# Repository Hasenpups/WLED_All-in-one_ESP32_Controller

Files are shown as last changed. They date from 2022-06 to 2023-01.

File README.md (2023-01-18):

Shield: [][cc-by-nc-sa]

This work is licensed under a
[Creative Commons Attribution-NonCommercial-ShareAlike 4.0 International License][cc-by-nc-sa].

[][cc-by-nc-sa]

[cc-by-nc-sa]: http://creativecommons.org/licenses/by-nc-sa/4.0/
[cc-by-nc-sa-image]: https://licensebuttons.net/l/by-nc-sa/4.0/88x31.png
[cc-by-nc-sa-shield]: https://img.shields.io/badge/License-CC%20BY--NC--SA%204.0-lightgrey.svg

## Donations / Spenden
If somebody wants to support me for upcoming projects :)  
- PayPal:  
- Amazon Giftcard: https://www.amazon.de/Amazon-Gutschein-per-E-Mail-Amazon/dp/B0054PDOV8 - stefan.riese@me.com

# WLED All-in-one ESP32 Controller
This board is designed to connect addressable LEDs/Neopixel strips and handle them with the WLED firmware. Other firmware can be used as well.

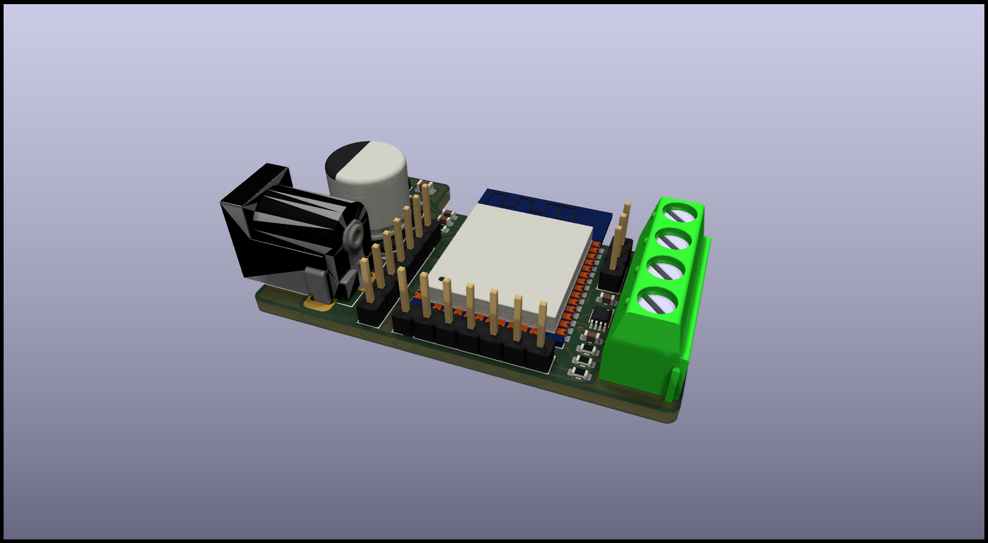
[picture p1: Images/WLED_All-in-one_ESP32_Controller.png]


## Features
- ESP32-WROOM-32E
- 5,5mm / 2,1mm barrel jack connector for input voltage
- 2 output lines for LED data and LED clock or relais
- level shifter for both outputs (3.3V -> 5V )
- resistor for data line
- support for LED strips with clock signal
- connector to flash firmware with CP2104 (3.3V, TX, RX, GND, IO0, GND)
- :heavy_exclamation_mark: Maximum 5A :heavy_exclamation_mark:
- connector for digital input (3.3V, GND, IO4) (IR remote control for example)
- connector for addon shields (GND, IO32, IO15, IO14, 3.3V, GND, SENSOR_VP)

## BOM
- 1 x WLED All-in-one ESP32 Controller presoldered from https://jlcpcb.com/

|Comment|Designator|Footprint|LCSC
|---|---|---|---
2.7K|R4|R_0603_1608Metric|C13167
100nF|C5,C6,C7|C_0603_1608Metric|C14663
47µF|C3|C_0805_2012Metric|C16780
10µF|C2,C4|C_0603_1608Metric|C19702
330|R5|R_0603_1608Metric|C23138
1000µF|C1|CP_Elec_10x10|C249474
10K|R1,R2,R3|R_0603_1608Metric|C25804
AMS1117-3.3|U1|SOT-89-3|C347256
TXS0102DCU|U3|VSSOP-8_2.3x2mm_P0.5mm|C53434
ESP32-WROOM-32|U2|ESP32-WROOM-32|C701342
LED|D1|LED_0805_2012Metric_Pad1.15x1.40mm_HandSolder|C84256
Barrel_Jack|J2|BarrelJack_Horizontal|
Screw_Terminal_01x04|J3|TerminalBlock_bornier-4_P5.08mm|
Conn_01x03_Female|J4|PinHeader_1x03_P2.54mm_Vertical|
Conn_01x07_Female|J1|PinHeader_1x07_P2.54mm_Vertical|
Conn_01x07_Female|J5|PinHeader_1x07_P2.54mm_Vertical|

- 2 x 2-pin screw terminal (https://www.amazon.de/gp/product/B08JB6SSCJ)
- 1 x Barrel Jack Adapter DS-210 (5,5mm / 2,1mm) (https://www.ebay.de/itm/182379482999)

## Wiring diagram
- https://github.com/Hasenpups/WLED_All-in-one_ESP32_Controller/blob/main/WLED_All-in-one_ESP32_Controller.pdf

## Software
- WLED: https://github.com/Aircoookie/WLED
- Sound reactive WLED: https://github.com/atuline/WLED 

## How to flash software
- Connect IO0 to GND
- Connect USB-UART bridge to 3.3V, TX, RX and GND
    - https://de.aliexpress.com/item/1005002689033373.html
    - https://www.makershop.de/module/kommunikation-module/micro-usb-uart-ttl/
- Open https://install.wled.me/
- Click "Install"
- Select COM port of USB-UART bridge
- Wait until finished

## WLED configuration
- OUT1 - IO16  
- OUT2 - IO17  
- IR receiver - IO18
- Digital microphone (SCK - IO14, WS - IO15, SD - IO32)
- Analog microphone (ADC - SENSOR_VP)
- Button input - IO26

## Addon shields
The following addon shields are available

### Microphone input
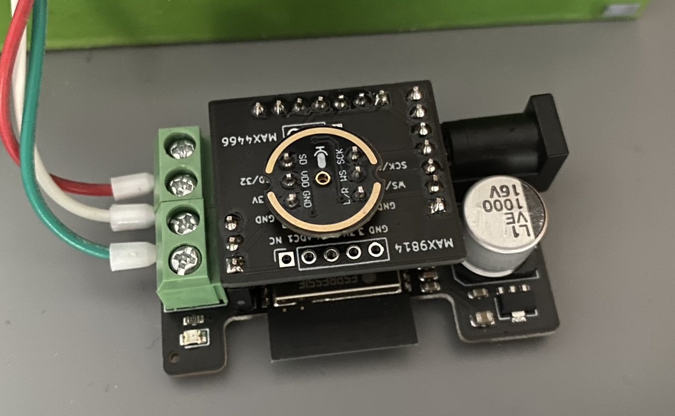
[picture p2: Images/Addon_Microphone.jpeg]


- connector for digital and analog microphones 
- INMP401 
- MAX4466 
- MAX9814 

### Prototype area
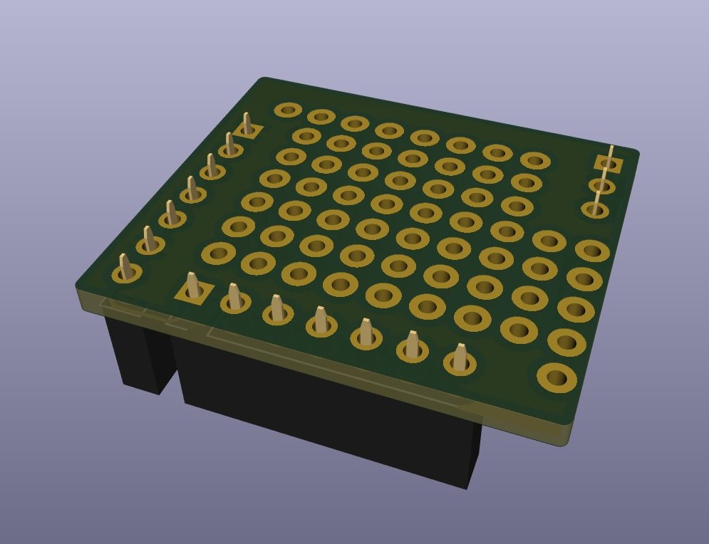
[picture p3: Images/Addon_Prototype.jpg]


### Cube builder
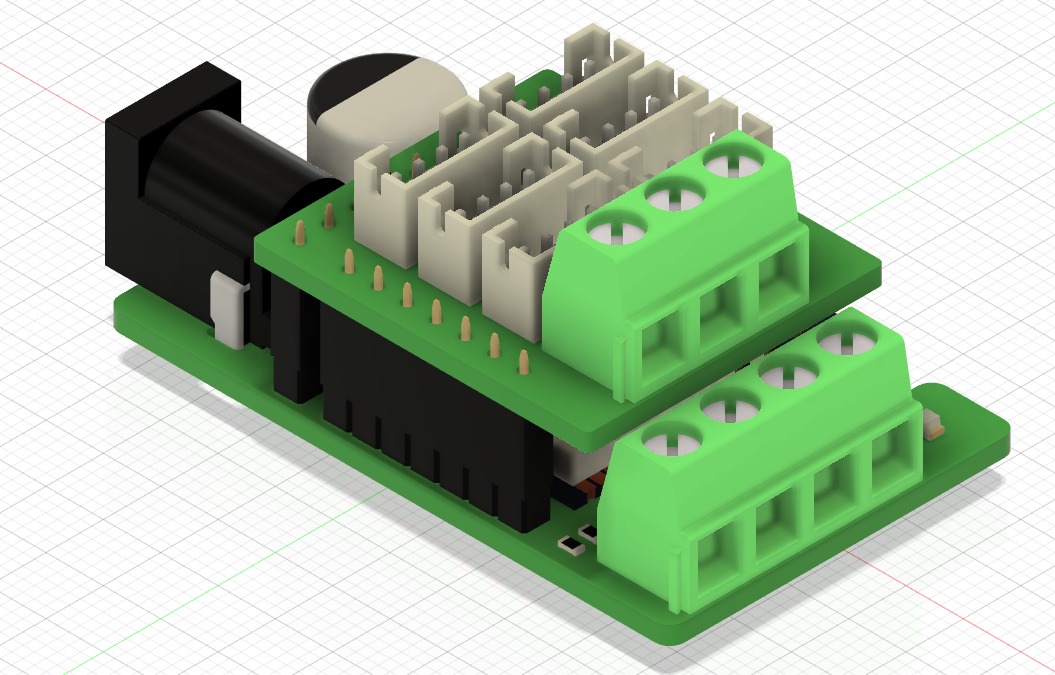
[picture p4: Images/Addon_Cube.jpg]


- 6 JST-PH connectors to add LED matrix panels to build a cube

## Case
https://www.printables.com/model/373138-wled-all-in-one-esp32-controller-housing

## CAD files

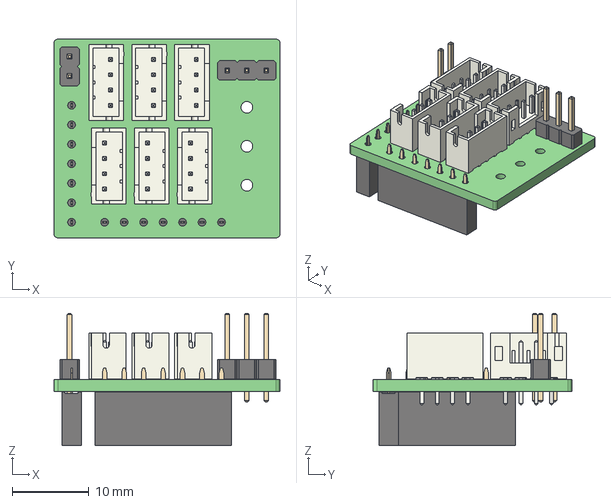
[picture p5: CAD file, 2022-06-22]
Addons/Cube/WLED_All-in-one_ESP32_Addon_Cube.step
29.5 x 25.9 x 17.2 mm
_autosave-WLED_All-in-one_ESP32_Addon_Cube PCB

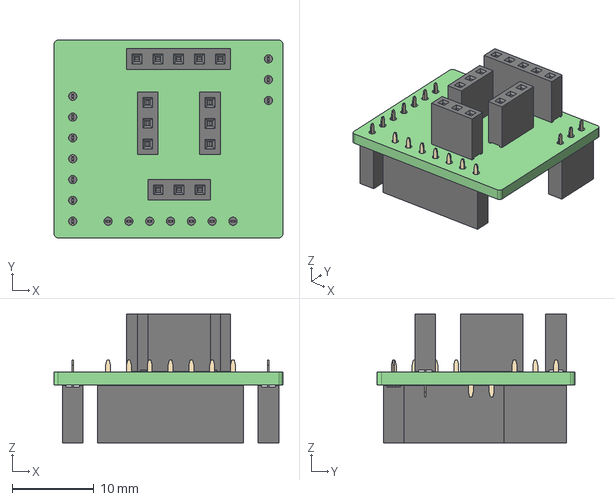
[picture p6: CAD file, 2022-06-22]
Addons/Microphone/WLED_All-in-one_ESP32_Addon_Microphone.step
27.9 x 24.1 x 15.7 mm
WLED_All-in-one_ESP32_Addon_Microphone PCB

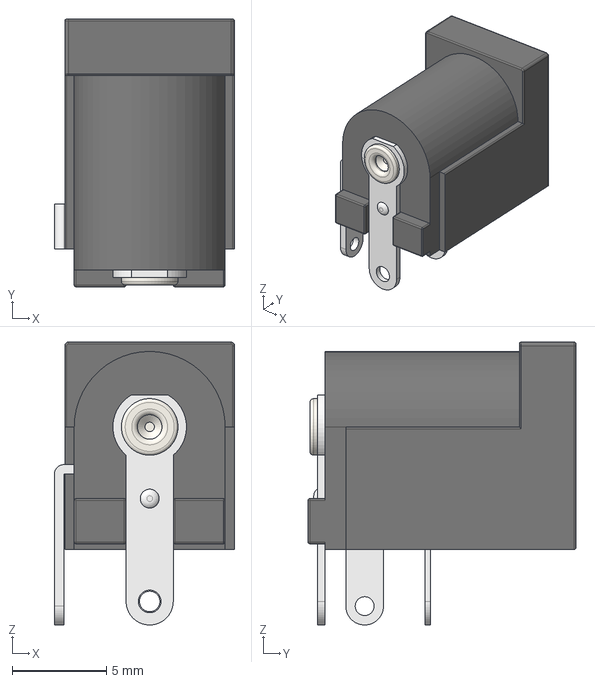
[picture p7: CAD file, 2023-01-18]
KiCad/Project_Libraries/Project_3DModels/DS-210 v1.step
9.55 x 14.2 x 15.0 mm

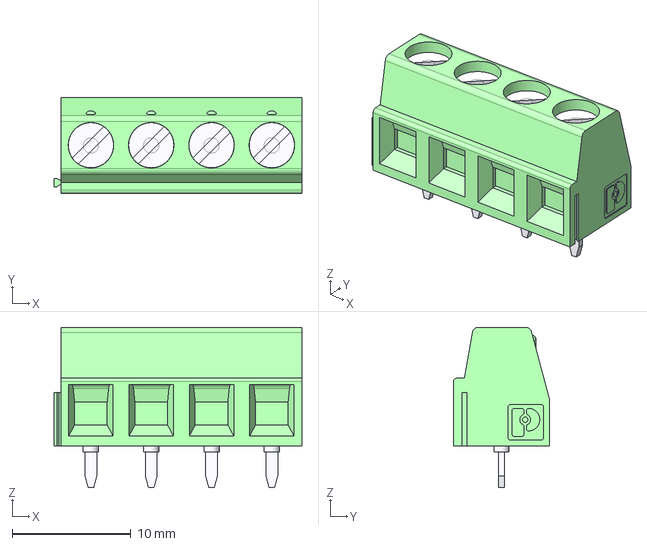
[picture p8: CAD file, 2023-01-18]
KiCad/Project_Libraries/Project_3DModels/PhoenixContact_MKDSN-1.5-4-5.08.step
20.9 x 8.10 x 13.5 mm

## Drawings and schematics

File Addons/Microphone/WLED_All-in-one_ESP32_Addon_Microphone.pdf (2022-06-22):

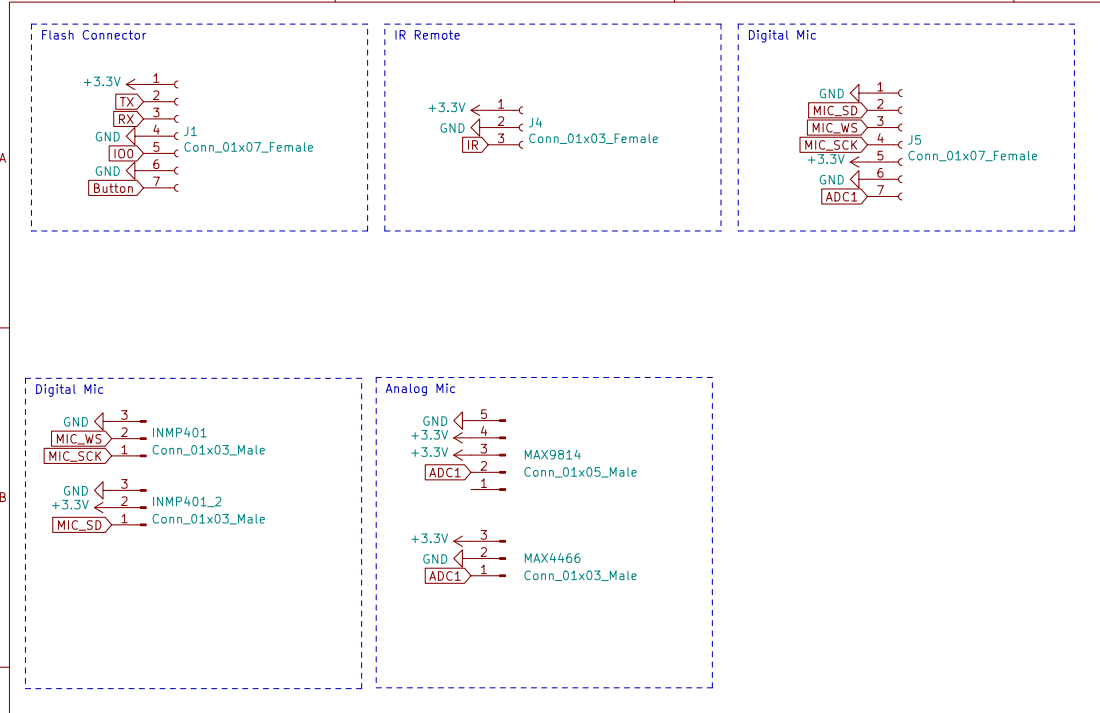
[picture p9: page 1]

IR Remote Digital Mic Flash Connector

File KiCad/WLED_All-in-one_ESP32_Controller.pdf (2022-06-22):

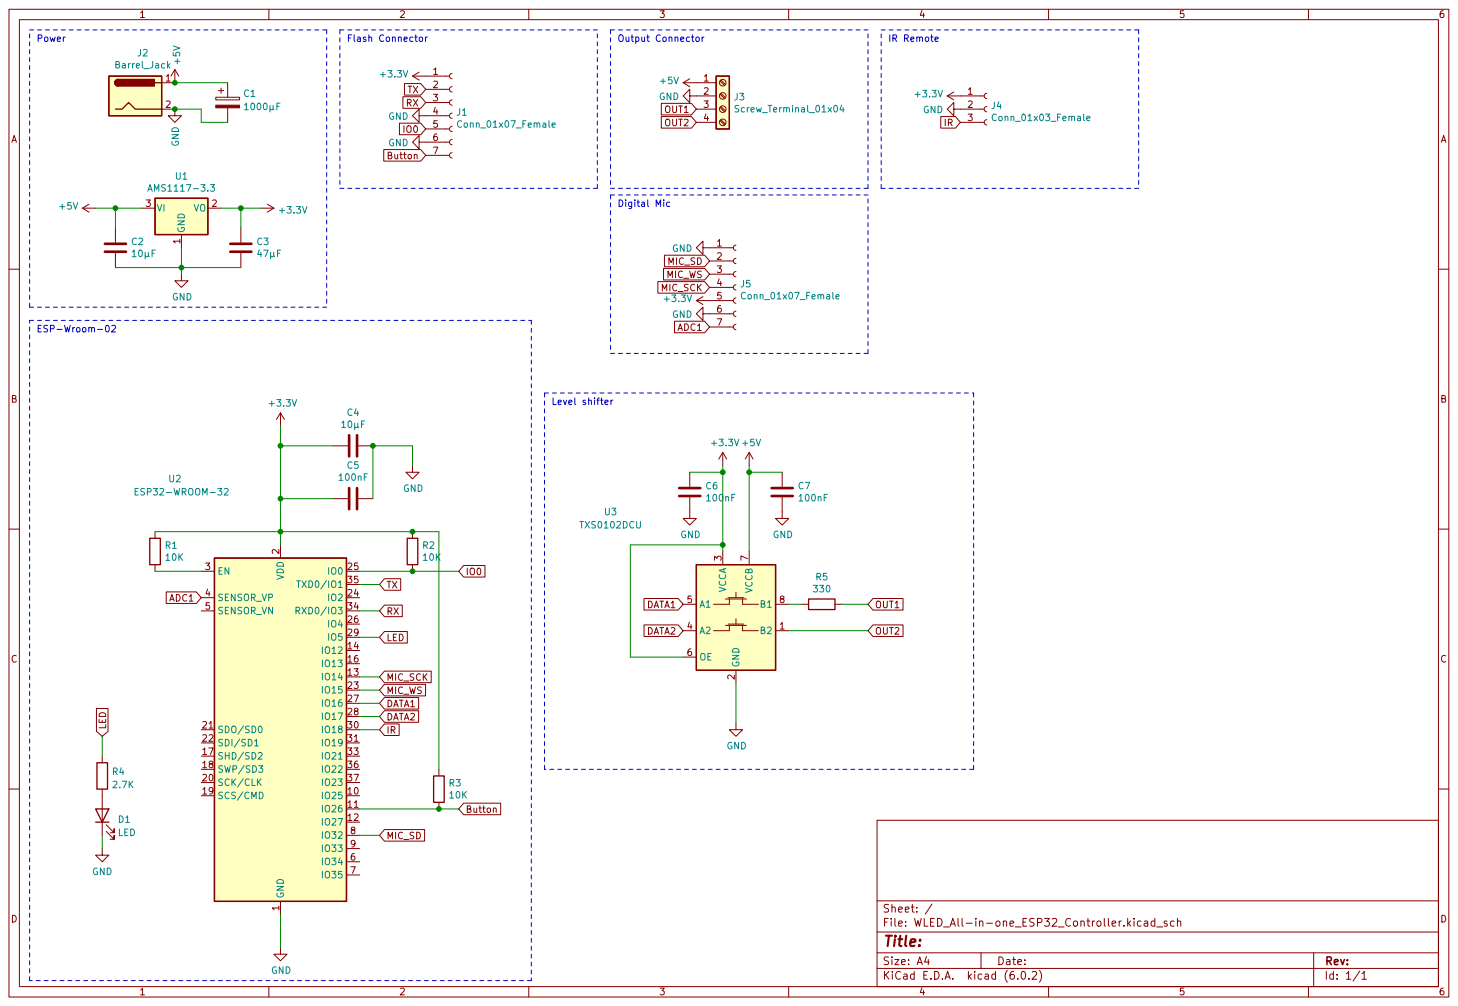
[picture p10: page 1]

IR Remote Digital Mic
ADC1 MIC_SCK OUT1 MIC_SD

2 SCK/CLK 20 SDO/SD0 21 SDI/SD1 22

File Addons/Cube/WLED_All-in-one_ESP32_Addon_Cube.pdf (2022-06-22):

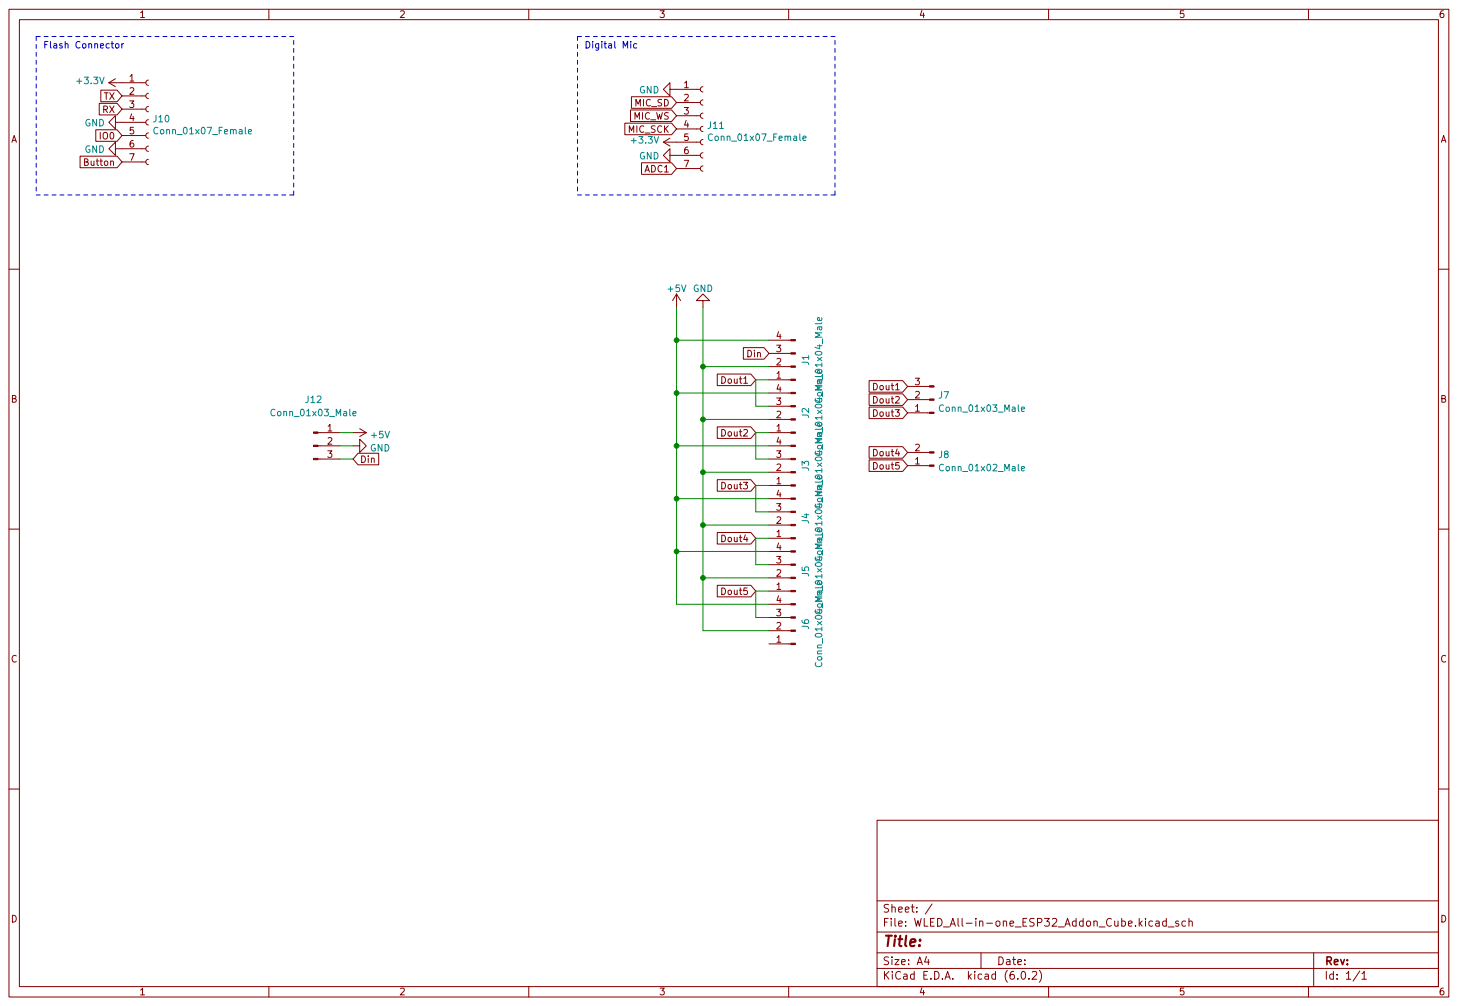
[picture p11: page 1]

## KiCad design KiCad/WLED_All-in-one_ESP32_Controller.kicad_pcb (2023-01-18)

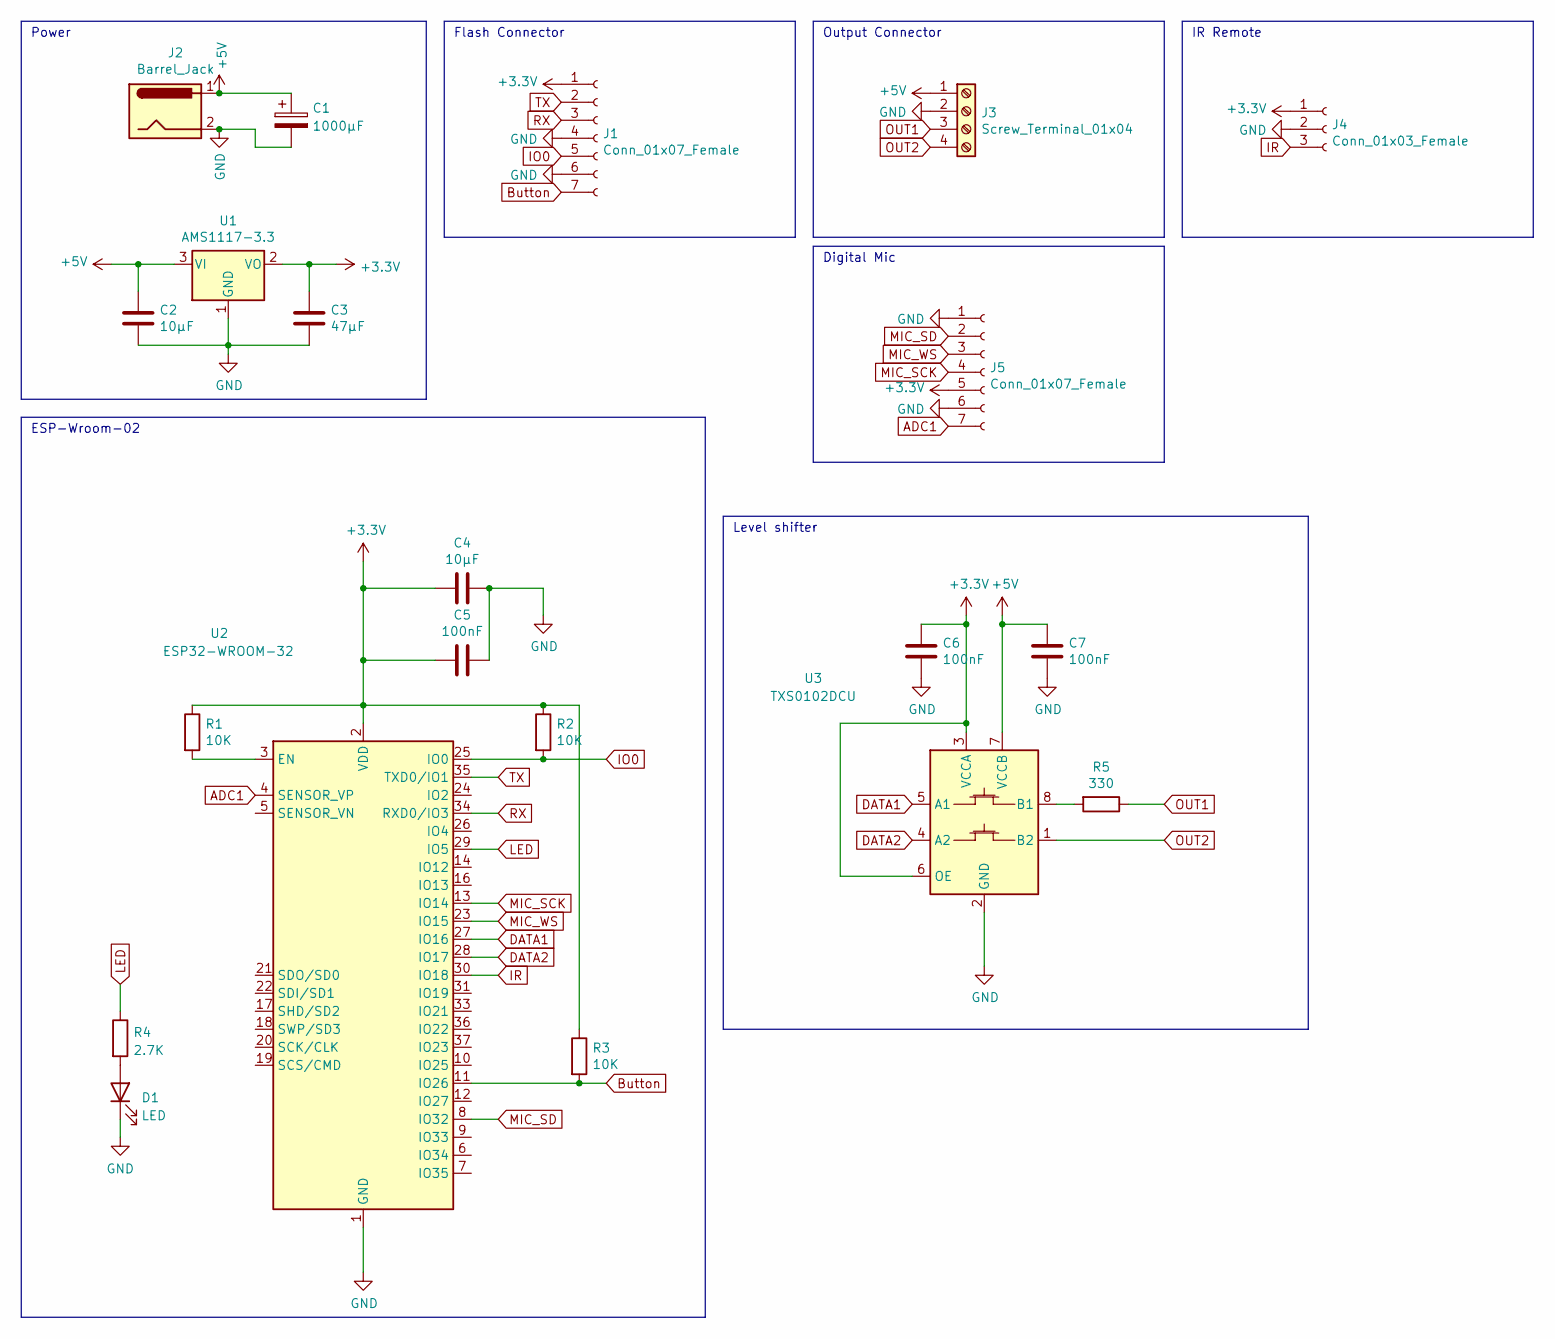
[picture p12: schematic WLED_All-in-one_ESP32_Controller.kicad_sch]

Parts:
C1: 1000µF; CP_Elec_10x10
C2, C4: 10µF; C_0603_1608Metric; LCSC C19702
C3: 47µF; C_0805_2012Metric; LCSC C16780
C5: 100nF; C_0603_1608Metric
C6, C7: 100nF; C_0603_1608Metric; LCSC C14663
D1: LED; LED_0805_2012Metric_Pad1.15x1.40mm_HandSolder; LCSC C84256
J1, J5: Conn_01x07_Female; PinHeader_1x07_P2.54mm_Vertical
J2: Barrel_Jack; BarrelJack_Horizontal
J3: Screw_Terminal_01x04; TerminalBlock_bornier-4_P5.08mm
J4: Conn_01x03_Female; PinHeader_1x03_P2.54mm_Vertical
R1, R2: 10K; R_0603_1608Metric; LCSC C25804
R3: 10K; R_0603_1608Metric
R4: 2.7K; R_0603_1608Metric; LCSC C13167
R5: 330; R_0603_1608Metric; LCSC C23138
U1: AMS1117-3.3; SOT-89-3; LCSC C347256
U2: ESP32-WROOM-32
U3: TXS0102DCU; VSSOP-8_2.3x2mm_P0.5mm; LCSC C53434

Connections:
+3V3: C3.1, C4.2, C5.2, C6.1, J1.1, J4.1, J5.5, R1.1, R2.1, R3.1, U1.2 (VO), U2.2 (VDD), U3.3 (VCCA), U3.6 (OE)
+5V: C1.1, C2.1, C7.1, J2.1, J3.1, U1.3 (VI), U3.7 (VCCB)
ADC1: J5.7, U2.4 (SENSOR_VP)
Button: J1.7, R3.2, U2.11 (IO26)
DATA1: U2.27 (IO16), U3.5 (A1)
DATA2: U2.28 (IO17), U3.4 (A2)
GND: C1.2, C2.2, C3.2, C4.1, C5.1, C6.2, C7.2, D1.1 (K), J1.4, J1.6, J2.2, J3.2, J4.2, J5.1, J5.6, U1.1 (GND), U2.1 (GND), U2.15 (GND), U2.38 (GND), U2.39 (GND), U3.2 (GND)
IO0: J1.5, R2.2, U2.25 (IO0)
IR: J4.3, U2.30 (IO18)
LED: R4.1, U2.29 (IO5)
MIC_SCK: J5.4, U2.13 (IO14)
MIC_SD: J5.2, U2.8 (IO32)
MIC_WS: J5.3, U2.23 (IO15)
unnamed: D1.2 (A), R4.2
unnamed: R1.2, U2.3 (EN)
unnamed: R5.2, U3.8 (B1)
OUT1: J3.3, R5.1
OUT2: J3.4, U3.1 (B2)
RX: J1.3, U2.34 (RXD0/IO3)
TX: J1.2, U2.35 (TXD0/IO1)

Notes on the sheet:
Flash Connector
IR Remote
Digital Mic
Power
ESP-Wroom-02
Level shifter
Output Connector

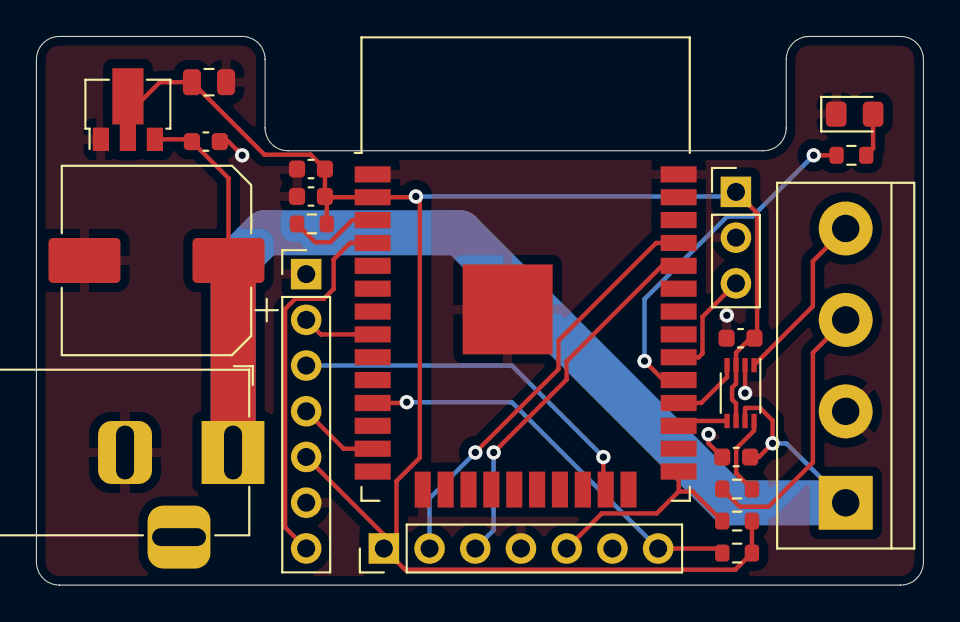
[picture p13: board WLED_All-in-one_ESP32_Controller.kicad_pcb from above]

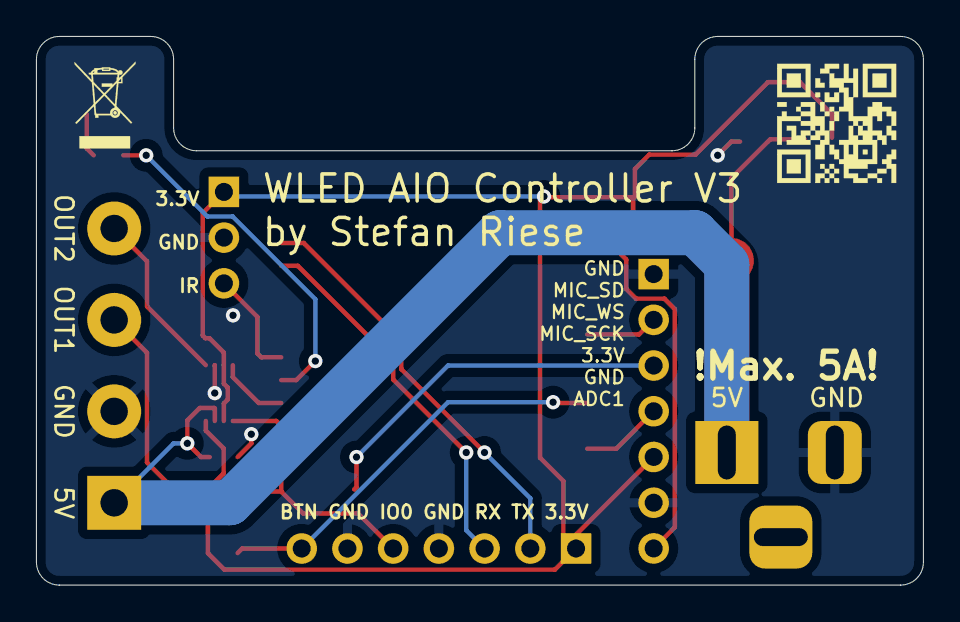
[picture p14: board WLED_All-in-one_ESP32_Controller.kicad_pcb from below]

Board: 2 copper layers, 49.3 x 30.5 mm, 23 parts (2 on the bottom side), 20 nets.

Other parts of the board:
G1: LOGO; github_hasenpups_qrcode
G2: LOGO; WEEE_Logo

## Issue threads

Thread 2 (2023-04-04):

IR function does not work

serb91, 2023-04-04:
hi, i have tried to set this board with my IR (KY-022) but it does not work.
Same settings I have also tried on another board and it works fine, for example this one > https://www.amazon.de/gp/product/B08CCYWZN3/
i have also tried to use the other Inputs, for example the IO which you have defined for a button > same here, no reaction
The LED on the IR-Receiver lights up, but nothing changes in WLED...

Hasenpups, 2023-05-03:
I can not reproduce this issue.

Closed 2023-05-03.

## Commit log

2022-06-22 - add addons
    [WLED_All-in-one_ESP32_Addon_Cube.step, WLED_All-in-one_ESP32_Addon_Microphone.step, WLED_All-in-one_ESP32_Addon_ProtoArea.step]
2023-01-18 - add JLCPCB files
    [BOM-WLED_All-in-one_ESP32_Controller.csv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]
2023-01-18 - add KiCad files
    [BOM-WLED_All-in-one_ESP32_Controller.csv, DS-210 v1.step, PhoenixContact_MKDSN-1.5-4-5.08.step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]

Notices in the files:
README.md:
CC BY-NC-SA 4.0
